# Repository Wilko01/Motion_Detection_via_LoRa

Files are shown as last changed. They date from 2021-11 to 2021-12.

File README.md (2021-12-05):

# Motion sensor communicating over LoRa
The challenge is to detect motion when someone enters the premise and send it over a longer distance to a location 50+m away where the residents are located and are triggered via a signal that someone is coming.

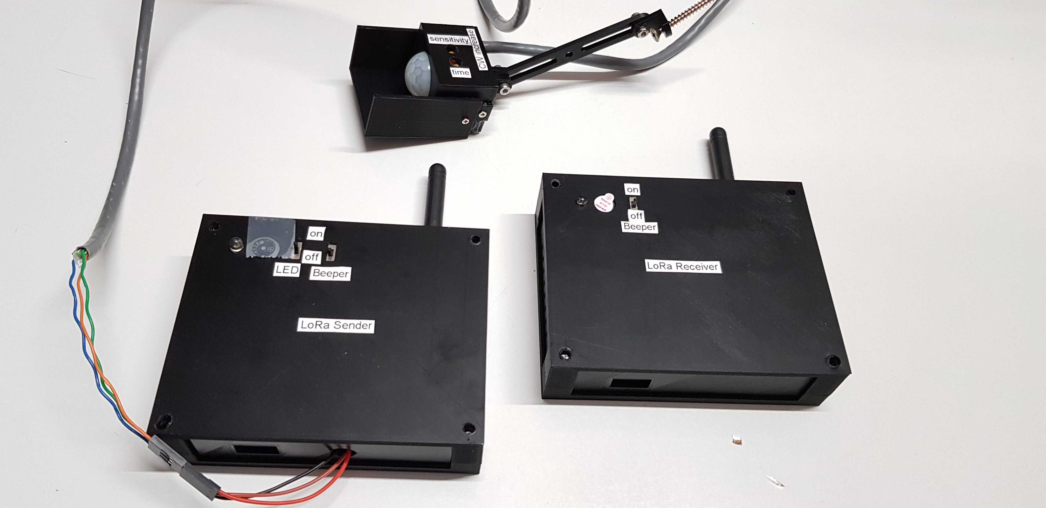
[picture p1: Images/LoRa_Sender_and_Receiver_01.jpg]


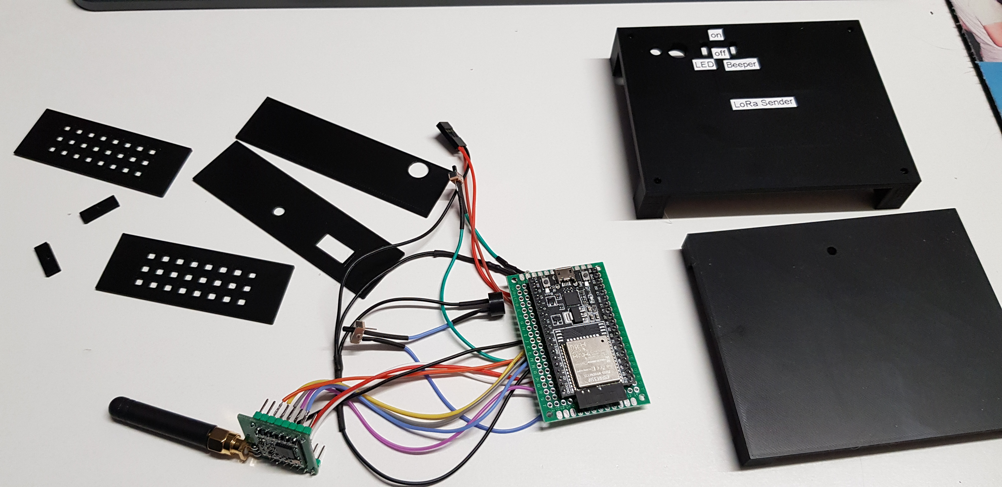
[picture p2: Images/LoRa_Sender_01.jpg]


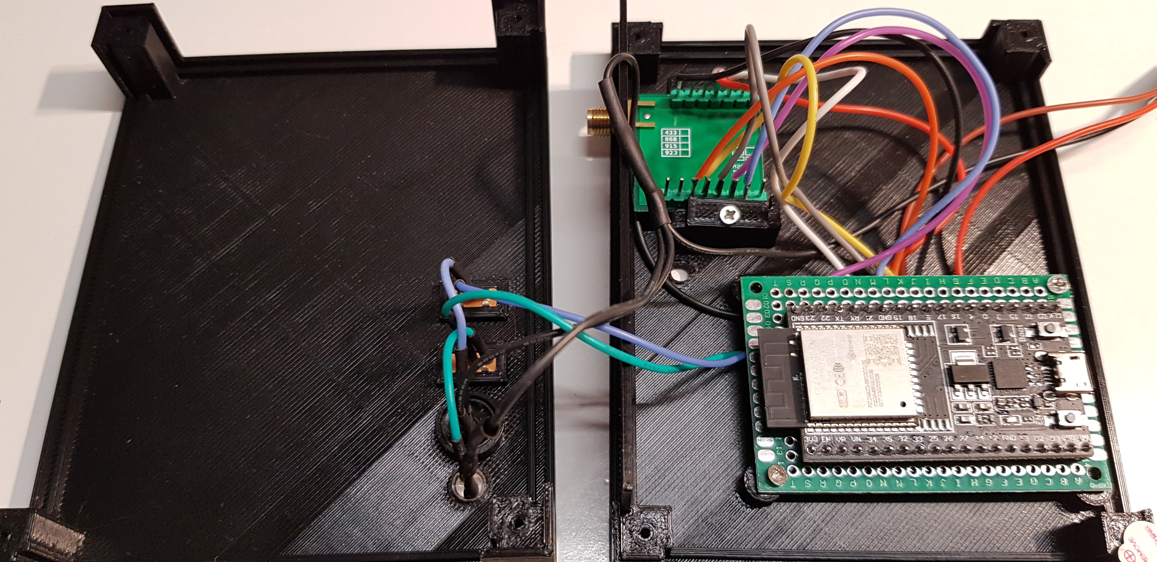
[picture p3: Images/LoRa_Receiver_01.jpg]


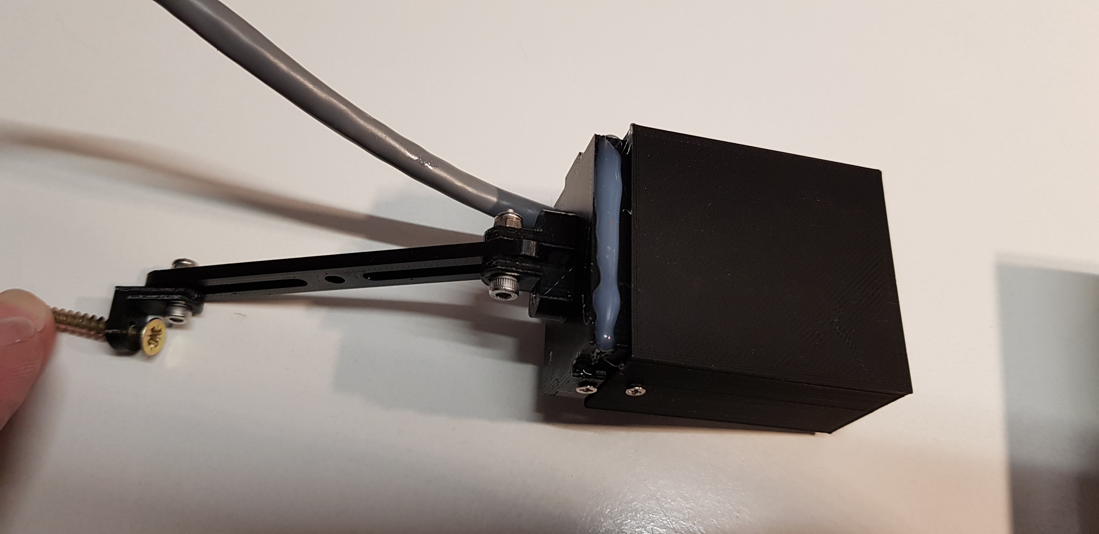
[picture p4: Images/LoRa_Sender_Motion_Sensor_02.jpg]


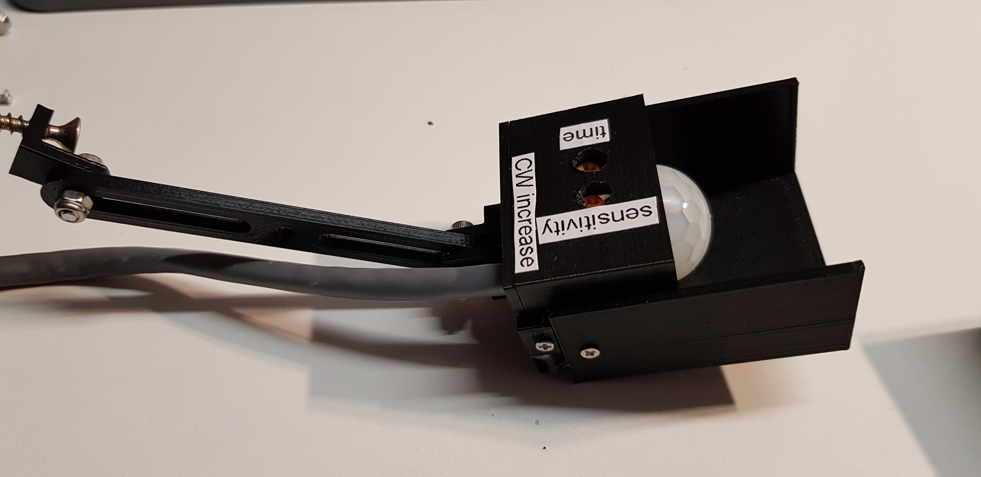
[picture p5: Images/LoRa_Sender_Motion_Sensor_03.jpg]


## Description and operation instructions
The motion sensor HC-SR501 in combination with LoRa RFM95W-868S2 transceiver is used to send a LoRa signal when motion is detected. At some distance the signal is received with a LoRa RFM95W-868S2 transceiver and LED and beeper will signal that the motion sensor was triggered. The RFM95W-868S2 are controlled via a ESP32-WROOM-32U at the transmitter and receiver.

 ## Technical description
The LoRa RFM95W-868S2 transceiver is connected to the ESP32-WROOM-32D

 ### LoRa Transmitter
| LoRa RFM95W-868S2 | ESP32 | LED + 3k3 risistor| 3,3V beeper | HC-SR501 | 
| ---|---|---|---| --- |
| GND | GND | GND | GND | |
| Reset | D14 | | | |
| NSS | D5 | | | |
| SCK | D18 | | | |
| MOSI | D23 | | | |
| MISO | D19 | | | |
| 3.3V | 3V3 | | | |
| DIO0 | 25 | | | |
| | | D26 | | |
| | | | D12 | |
| | | | | D27 |

### LoRa Receiver
| LoRa RFM95W-868S2 | ESP32 | LED + 3k3 risistor| 3,3V beeper | 
| ---|---|---|---|
| GND | GND | GND | GND |
| Reset | D14 | | |
| NSS | D5 | | |
| SCK | D18 | | |
| MOSI | D23 | | |
| MISO | D19 | | |
| 3.3V | 3V3 | | |
| DIO0 | 25 | | |
| | | D26 | |
| | | | D12 |
| | | | |

### Parts
- 1 x ESP32-WROOM-32U

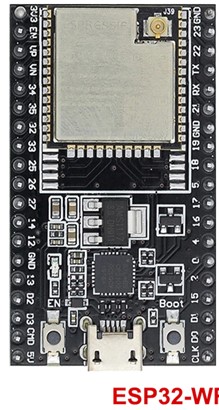
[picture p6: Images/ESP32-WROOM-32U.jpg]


### Schematic overview
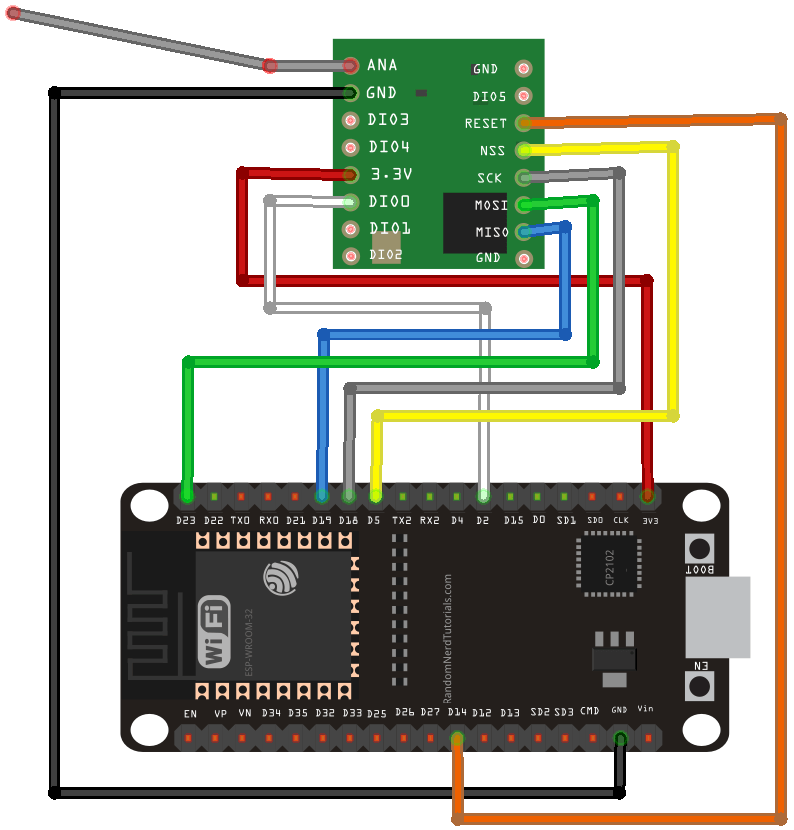
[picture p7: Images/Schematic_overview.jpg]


The drawing is not completely correct as Pin DIO0 is connected to 25 as listed in the table above. I was lasy and copied the drawing from Randomtutorials. Which I'm thankfull for good instructions to get me started.

### ESPHome installation
See the instructions https://github.com/Wilko01/ESPHome  (not listed here)

### ESPHome Configuration in Home Assistant
Create a new device  with this code:

### Interface
There is no interface with anything as this needs to run stand-alone.

### Testing
Place it somewhere were motion is and check if the signal comes in.

## 3D printer files
It all started by measuring the air quality when printing, so the 3D printer files must be included in this project:
- [3D files include the Sketchup make file as well as the 3D print files .STL](/3D_Printer_Files)
- [Thingiverse](https://www.thingiverse.com/thing:5155707)

### Information

Generic
- [Markdown Cheat Sheet](https://www.markdownguide.org/cheat-sheet/)

### Problems
- The receiver did not respond after 2 to 3 hours. 
    On 05-12-2021 Disabled almost all 'print to serial' commands. Printing of Strings takes a lot of memory, hence commented out all the print to serial commands which are not in the setup loop.

### Wishlist
..

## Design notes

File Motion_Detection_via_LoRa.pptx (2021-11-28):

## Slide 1

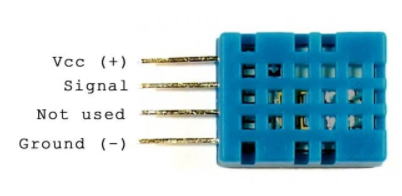
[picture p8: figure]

4.7k

Air quality
Mutation date 08-11-2021

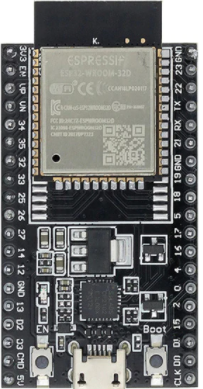
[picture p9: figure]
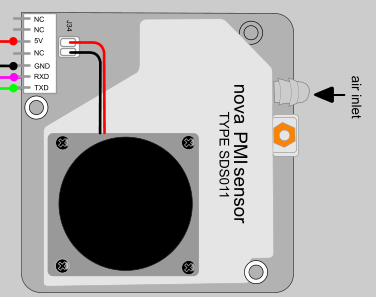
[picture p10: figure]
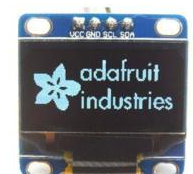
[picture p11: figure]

Cable as capacitive touch

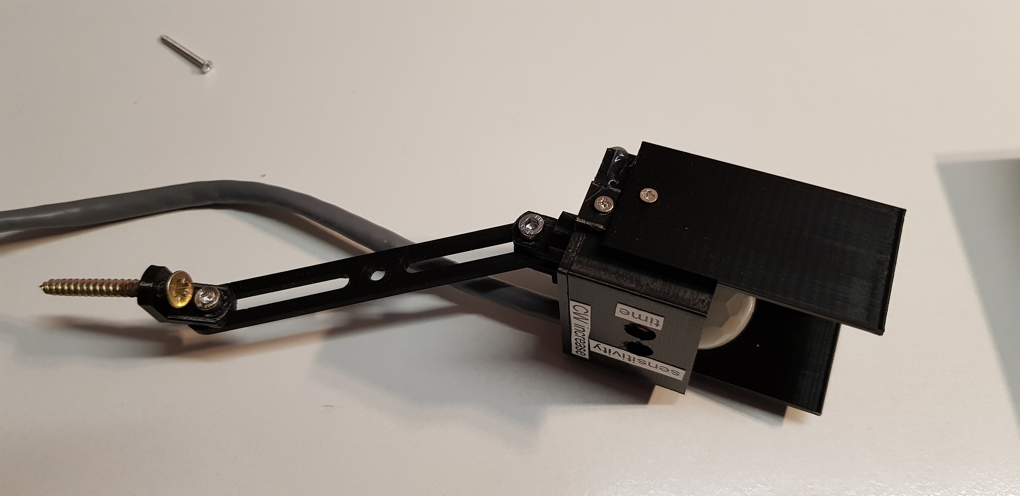
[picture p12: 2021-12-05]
Images/LoRa_Sender_Motion_Sensor_01.jpg

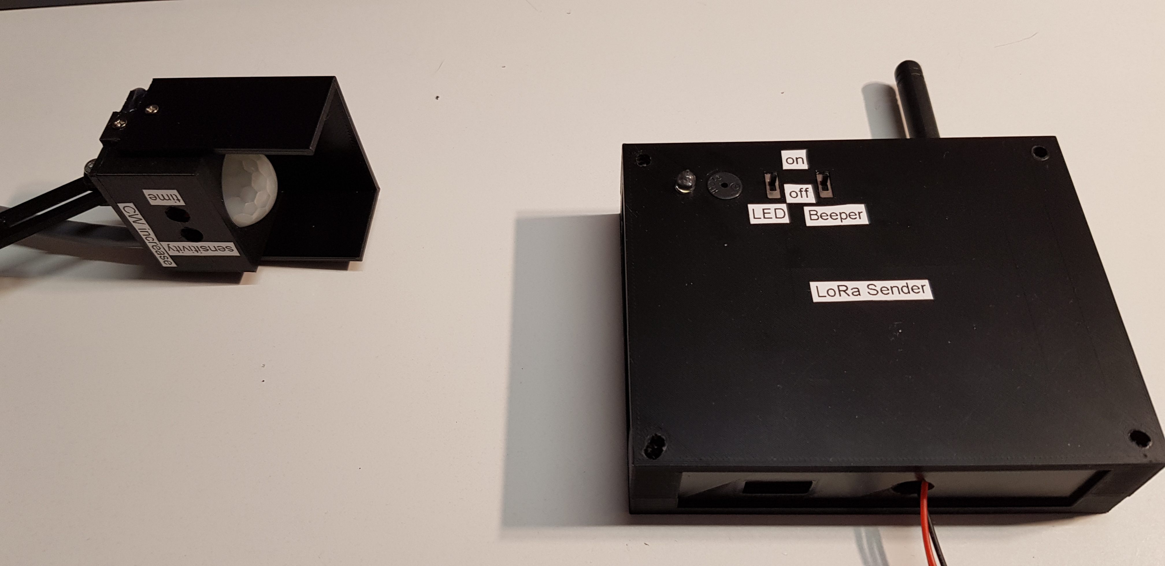
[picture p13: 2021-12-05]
Images/LoRa_Sender_02.jpg

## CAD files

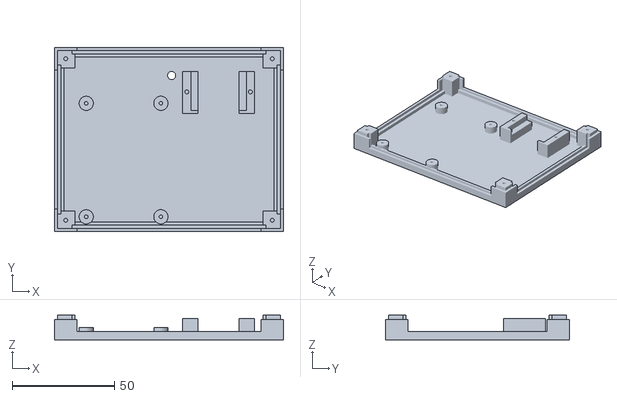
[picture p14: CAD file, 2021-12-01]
3D_Printer_Files/Motion_Detection_via_LoRa_Receiver_Box_Main_Body.stl
112.0 x 90.0 x 12.0

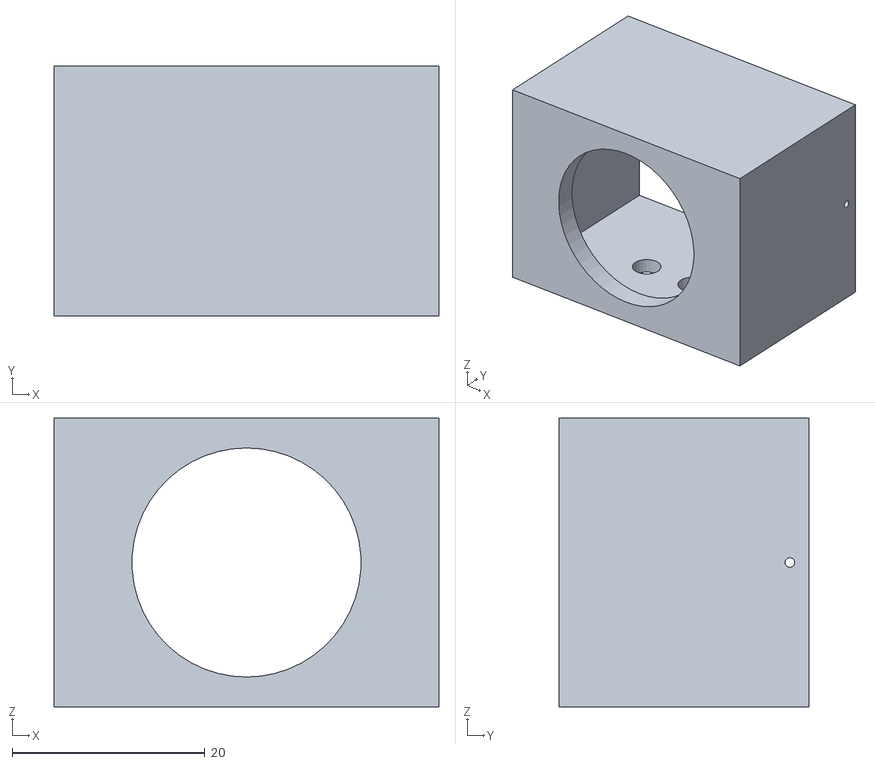
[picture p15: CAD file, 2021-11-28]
3D_Printer_Files/Motion_Detection_via_LoRa_Motion_Box_main_body.stl
40.0 x 26.0 x 30.0

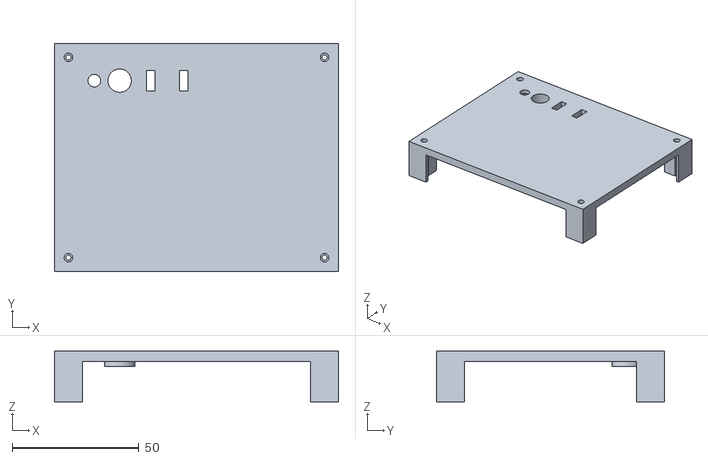
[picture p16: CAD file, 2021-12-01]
3D_Printer_Files/Motion_Detection_via_LoRa_Sender_Box_Top.stl
112.0 x 90.0 x 20.0

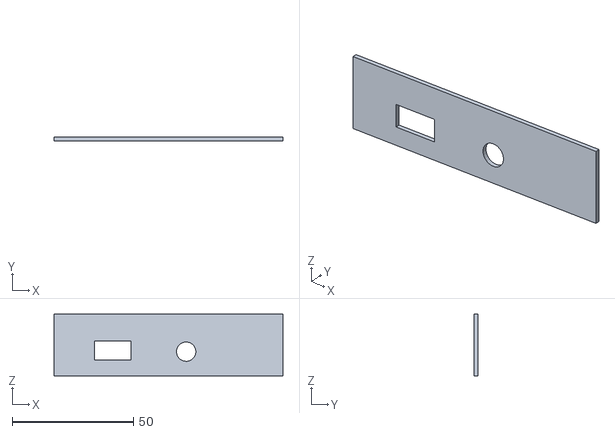
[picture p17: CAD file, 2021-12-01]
3D_Printer_Files/Motion_Detection_via_LoRa_Sender_Box_Bottom_insert.stl
94.6 x 1.50 x 25.5

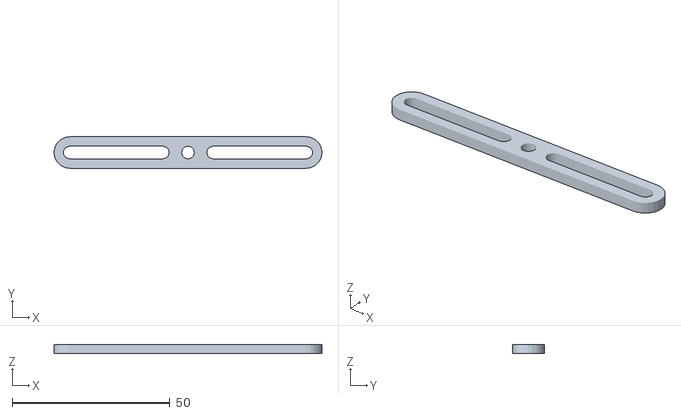
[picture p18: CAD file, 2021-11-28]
3D_Printer_Files/Motion_Detection_via_LoRa_Motion_Box_connection_bar.stl
85.0 x 10.0 x 3.00

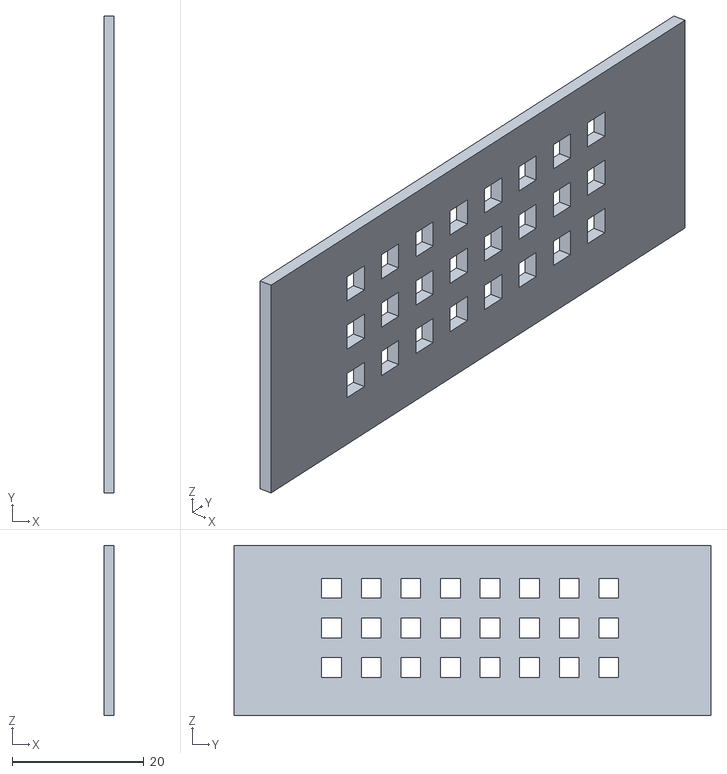
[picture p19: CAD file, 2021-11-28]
3D_Printer_Files/Motion_Detection_via_LoRa_Sender_Box_Side_insert.stl
1.50 x 72.3 x 25.8

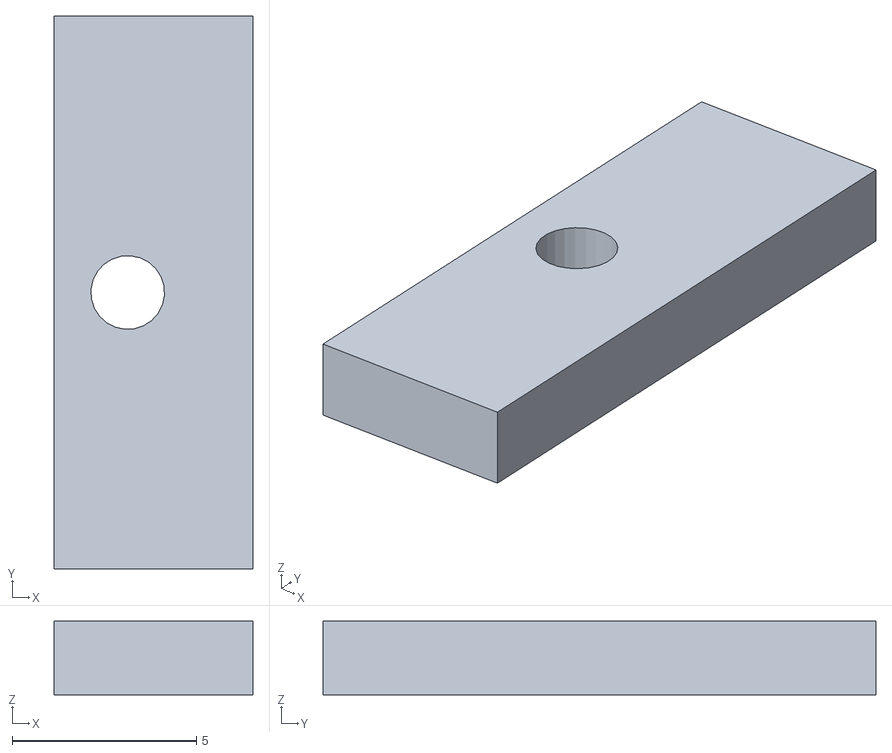
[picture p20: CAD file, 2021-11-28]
3D_Printer_Files/Motion_Detection_via_LoRa_Sender_Box_clamp_for_LoRa_RFM95.stl
5.40 x 15.0 x 2.00

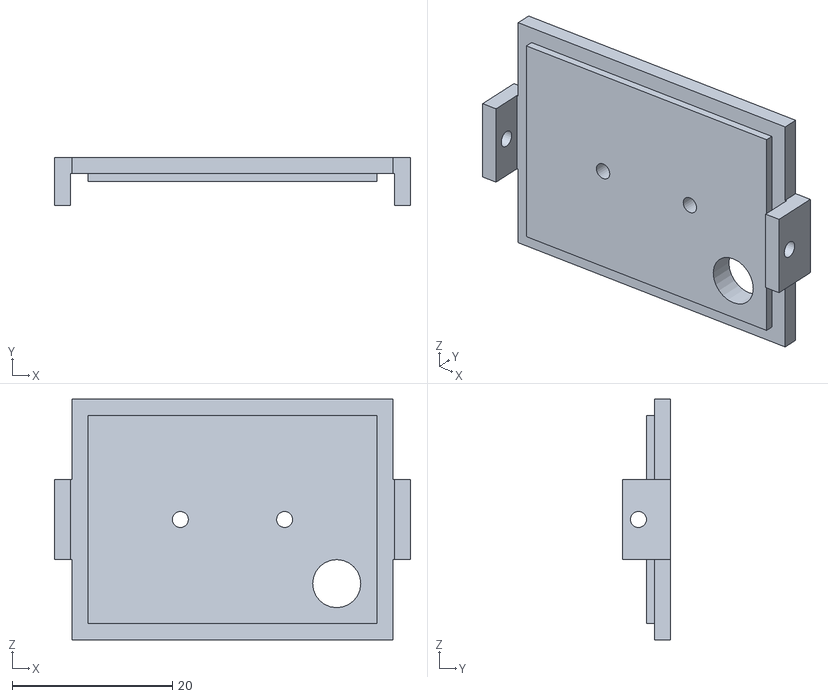
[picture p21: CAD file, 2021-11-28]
3D_Printer_Files/Motion_Detection_via_LoRa_Motion_Box_bottom_shield.stl
44.4 x 6.00 x 30.0

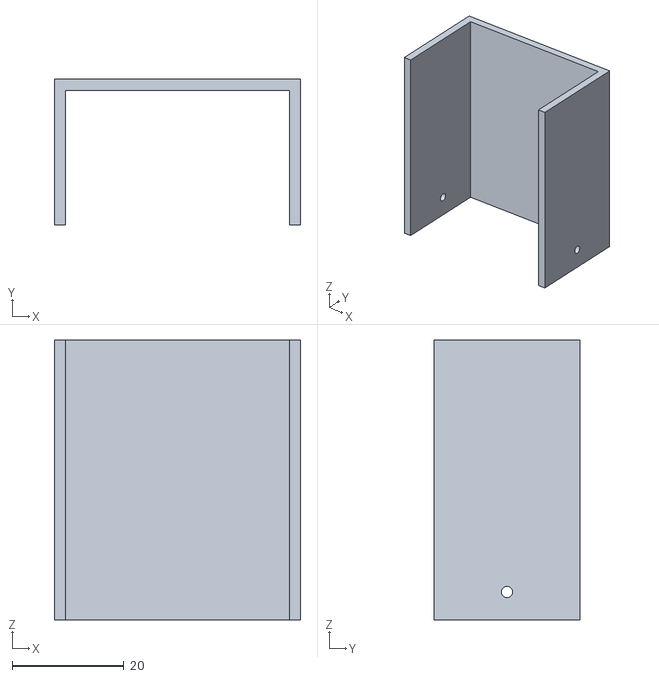
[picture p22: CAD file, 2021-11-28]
3D_Printer_Files/Motion_Detection_via_LoRa_sun_shield.stl
44.0 x 26.0 x 50.0

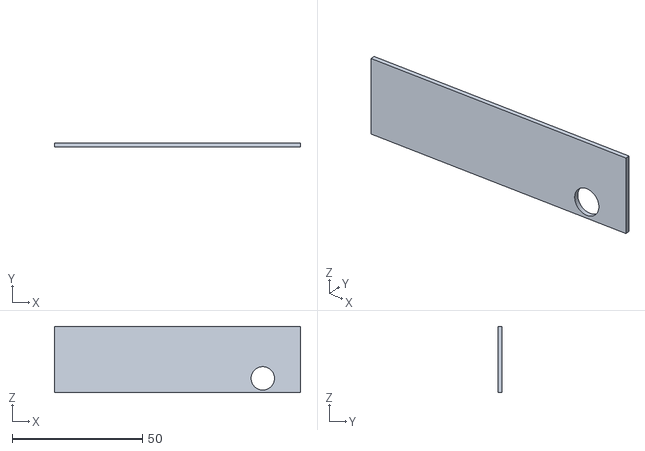
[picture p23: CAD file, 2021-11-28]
3D_Printer_Files/Motion_Detection_via_LoRa_Sender_Box_Top_insert.stl
94.6 x 1.50 x 25.5

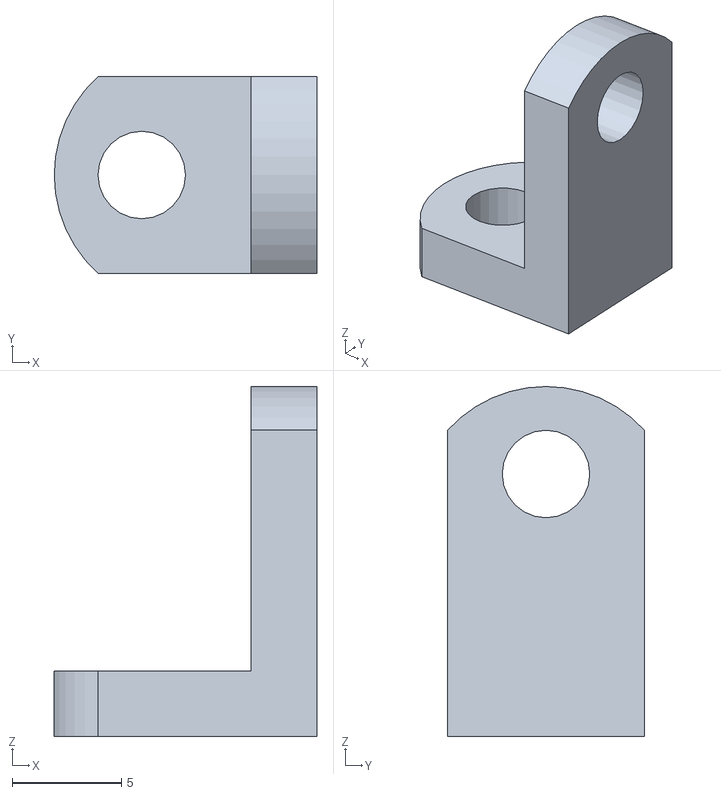
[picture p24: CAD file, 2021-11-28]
3D_Printer_Files/Motion_Detection_via_LoRa_Motion_Box_hook_wall.stl
12.0 x 9.00 x 16.0

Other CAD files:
3D_Printer_Files/Motion_Detection_via_LoRa_Sender_Box_Main_Body.stl
3D_Printer_Files/Motion_Detection_via_LoRa_Motion_Box_hook_main_body.stl
3D_Printer_Files/Motion_Detection_via_LoRa_Receiver_Box_Bottom_insert.stl
3D_Printer_Files/Motion_Detection_via_LoRa.skp

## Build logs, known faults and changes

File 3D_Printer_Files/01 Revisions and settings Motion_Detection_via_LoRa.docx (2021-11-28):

# Print settings:

- Print material: PLA
- Rotation of the objects: No comment.
- Support: No
- Skirt, brim: Skirt.

# Additional instructions

# Materials needed

- PLA

# Version 0.2

12-11-2021

- Shortened the width of the side parts with 0.2mm for a better fit
- Reduced the width of the LCD gap in the front for a better fit
- Reduced the holes for the screws holding the SDS011 to fit 3mm screws

# Version 0.1

- First release

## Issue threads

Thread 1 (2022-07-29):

Move 20000 delay in the receiver to be in the if motion received part as it is now outside and holds the loop.

Wilko01, 2022-07-29:
Best to remove the delay and replace it with a timer.

Wilko01, 2022-07-29:
Delay was already commented out, hence problem was not existing

Wilko01, 2022-07-29:
Delay was already commented out, hence problem was not existing

Closed 2022-07-29.

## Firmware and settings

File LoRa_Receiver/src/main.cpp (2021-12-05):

#include <Arduino.h>

/*********
  Modified from the examples of the Arduino LoRa library
  More resources: https://randomnerdtutorials.com
  05-12-2021 The print to serial commands are almost all disabled. When they were enabled
   the ESP32 did not respons after 2 to 3 hours.
  Receiver
*********/

#include <SPI.h>
#include <LoRa.h>

//define the pins used by the transceiver module
#define ss 5
#define rst 14
#define dio0 25

// Set GPIOs for LED and beeper
const int led = 26;
const int beeper = 12;

//String LoRaData; // used to store the received data

void setup() {
  //initialize Serial Monitor
  Serial.begin(115200);
  while (!Serial);
  Serial.println("LoRa Receiver");
  Serial.println("Project: Motion_Detection_via_Lora Receiver code");

  //setup LoRa transceiver module
  LoRa.setPins(ss, rst, dio0);
  
  //replace the LoRa.begin(---E-) argument with your location's frequency 
  //866E6 for Europe
  while (!LoRa.begin(866E6)) {
    Serial.println(".");
    delay(500);
  }
   // Change sync word (0xF3) to match the receiver
  // The sync word assures you don't get LoRa messages from other LoRa transceivers
  // ranges from 0-0xFF
  LoRa.setSyncWord(0x99); //customized to 99
  Serial.println("LoRa Initializing OK!");

    // Set LED and beeper to LOW
  pinMode(led, OUTPUT);
  digitalWrite(led, LOW);
  pinMode(beeper, OUTPUT);
  digitalWrite(beeper, LOW);
}

void loop() {
  String LoRaData; // used to store the received data
  // try to parse packet
  int packetSize = LoRa.parsePacket();
  if (packetSize) {
    // received a packet
    //Serial.print("Received packet: '");
    // read packet
    while (LoRa.available()) {
      LoRaData = LoRa.readString();
    }
      if (LoRaData == "motion"){
        digitalWrite(led, HIGH);
        digitalWrite(beeper, HIGH);
        delay(2000);
        digitalWrite(led, LOW);
        digitalWrite(beeper, LOW);
      } 
      //Serial.print(LoRaData);
      //Serial.print("'");
      // print RSSI of packet
      //Serial.print(" with RSSI ");
      //Serial.println(LoRa.packetRssi());
    }
    //Serial.println("Pauze 20 sec to not get overwelmed by the triggers");
    //delay(20000); 
}

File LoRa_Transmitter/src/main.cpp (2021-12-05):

#include <Arduino.h>

/*********
   Info: 
  - https://github.com/sandeepmistry/arduino-LoRa
  - https://github.com/sandeepmistry/arduino-LoRa/blob/master/API.md

  Modified from the examples of the Arduino LoRa library
  More resources: https://randomnerdtutorials.com
  Transmitter
*********/

#include <SPI.h>
#include <LoRa.h>

//define the pins used by the transceiver module
#define ss 5
#define rst 14
#define dio0 25

// Set GPIOs for LED and PIR Motion Sensor
const int beeperPin = 12;
const int ledPin = 26;
const int motionSensorPin = 27;

// variable for storing the motion sensor status 
int motionSensorState = 0;

void setup() {
  //initialize Serial Monitor
  Serial.begin(115200);
  while (!Serial);
  Serial.println("LoRa Sender");
  Serial.println("Project: Motion_Detection_via_Lora Transmitter code");

  //setup LoRa transceiver module
  LoRa.setPins(ss, rst, dio0);
  
  //replace the LoRa.begin(---E-) argument with your location's frequency 
  //866E6 for Europe
   while (!LoRa.begin(866E6)) {
    Serial.println(".");
    delay(500);
  }
   // Change sync word (0xF3) to match the receiver
  // The sync word assures you don't get LoRa messages from other LoRa transceivers
  // ranges from 0-0xFF
  LoRa.setSyncWord(0x99); //customized to 99
  Serial.println("LoRa Initializing OK!");

// Set beeper to LOW
  pinMode(beeperPin, OUTPUT);
  digitalWrite(beeperPin, LOW);
  
  // Set LED to LOW
  pinMode(ledPin, OUTPUT);
  digitalWrite(ledPin, LOW);

  // Set motionSensorPin as input
  pinMode(motionSensorPin, INPUT);
}

void loop() {
  //read the motion state
  motionSensorState = digitalRead(motionSensorPin);
 // Serial.print("motionSensorState = ");
 // Serial.println(motionSensorState);
  // check if motion is detected
  // if it is, the motionSensorState is HIGH
  if (motionSensorState == HIGH) {
     // detectsMovement(); //send Lora message, set LED and beeper high
     Serial.println("MOTION DETECTED send!");
    //Send LoRa packet to receiver
    LoRa.beginPacket();
    LoRa.print("motion"); //send the word motion via LoRa
    LoRa.endPacket();
    digitalWrite(ledPin, HIGH); //turn the led high for visual debugging
    digitalWrite(beeperPin, HIGH); //turn the led high
    delay(2000);
    digitalWrite(ledPin, LOW);
    digitalWrite(beeperPin, LOW);
      delay(5000);
    } else { //No motion so set low
      digitalWrite(ledPin, LOW);
    }
//      delay(1000);
     }
    
 
